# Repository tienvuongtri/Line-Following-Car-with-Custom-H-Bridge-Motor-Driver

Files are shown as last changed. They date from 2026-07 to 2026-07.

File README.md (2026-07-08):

# ESP32 Line-Following Robot with Custom H-Bridge

An autonomous and Bluetooth-controlled 4WD robot featuring a custom-designed H-Bridge motor driver, ultrasonic obstacle detection, and PID-based line tracking.

## 🛠️ Hardware Overview

* **Microcontroller:** ESP32 Development Board
* **Motor Driver:** Custom-designed L298N H-Bridge PCB
* **Line Sensor:** 5-Channel IR Sensor Array (Active Low logic)
* **Obstacle Detection:** HC-SR04 Ultrasonic Sensor
* **Actuators/Indicators:** 4x DC Motors, Buzzer, LED Indicator
* **Communication:** Bluetooth Classic (`ESP32_PRO_CAR`)

## 📍 Pin Mapping

| Component | ESP32 Pin | Component | ESP32 Pin |
| :--- | :--- | :--- | :--- |
| **Motor ENA** | GPIO 14 | **Sensor S1 (Far Left)** | GPIO 17 |
| **Motor ENB** | GPIO 32 | **Sensor S2 (Mid Left)** | GPIO 19 |
| **Motor IN1** | GPIO 27 | **Sensor S3 (Center)** | GPIO 4 |
| **Motor IN2** | GPIO 26 | **Sensor S4 (Mid Right)** | GPIO 16 |
| **Motor IN3** | GPIO 25 | **Sensor S5 (Far Right)**| GPIO 23 |
| **Motor IN4** | GPIO 33 | **Ultrasonic TRIG** | GPIO 5 |
| **Buzzer** | GPIO 15 | **Ultrasonic ECHO** | GPIO 18 |
| **LED** | GPIO 2 | | |

## 📂 Project Structure

* `xe_do_line_IC2005_G1/`: Arduino source code containing the PID algorithm, Bluetooth control logic, and sensor reading functions.
* `H-Bridge Module/`: KiCad 9 hardware design files, including schematics, PCB layout, and Gerber files for manufacturing the custom motor driver.
* `images/`: Real-world photos and 3D renderings of the hardware.

## 📸 Demonstration

**Custom H-Bridge PCB Design:**
<div align="center">
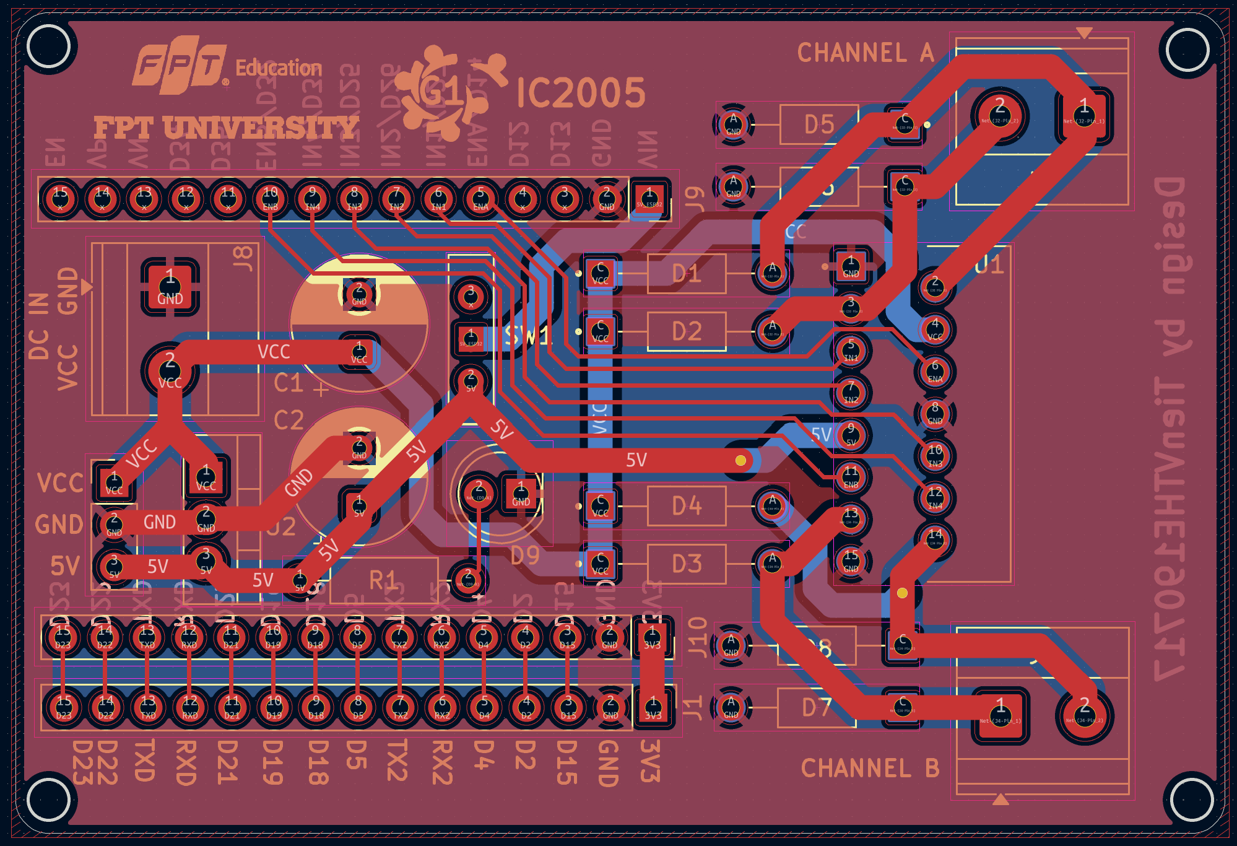
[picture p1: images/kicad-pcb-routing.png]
PCB Layout
  
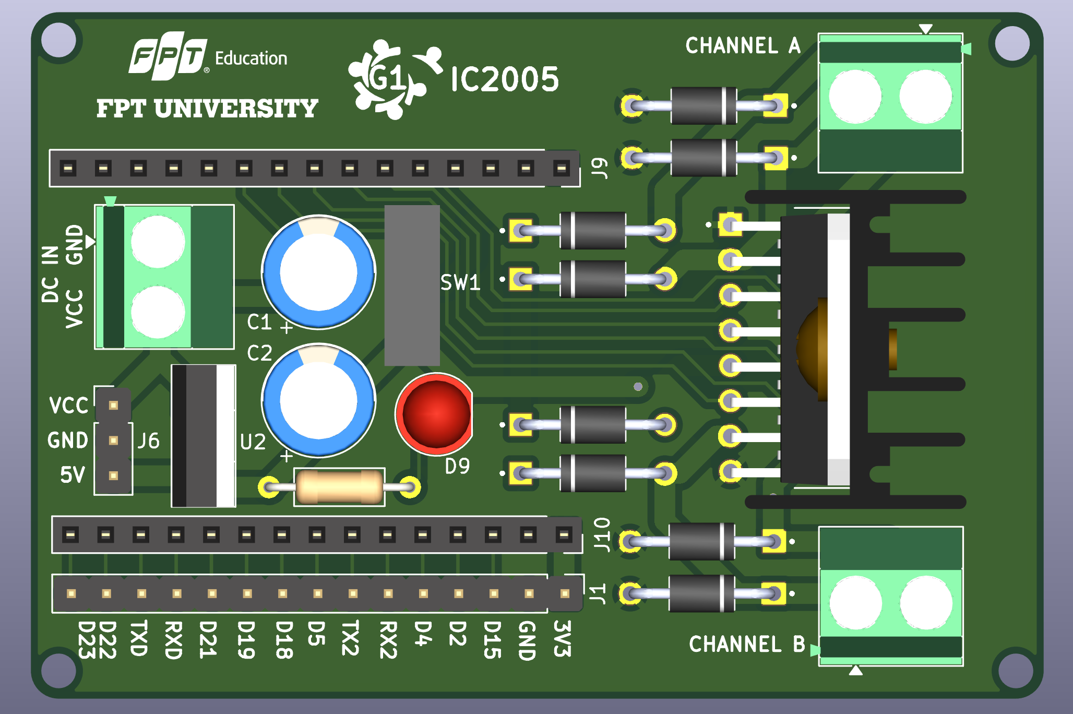
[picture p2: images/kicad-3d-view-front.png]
3D Front View
  
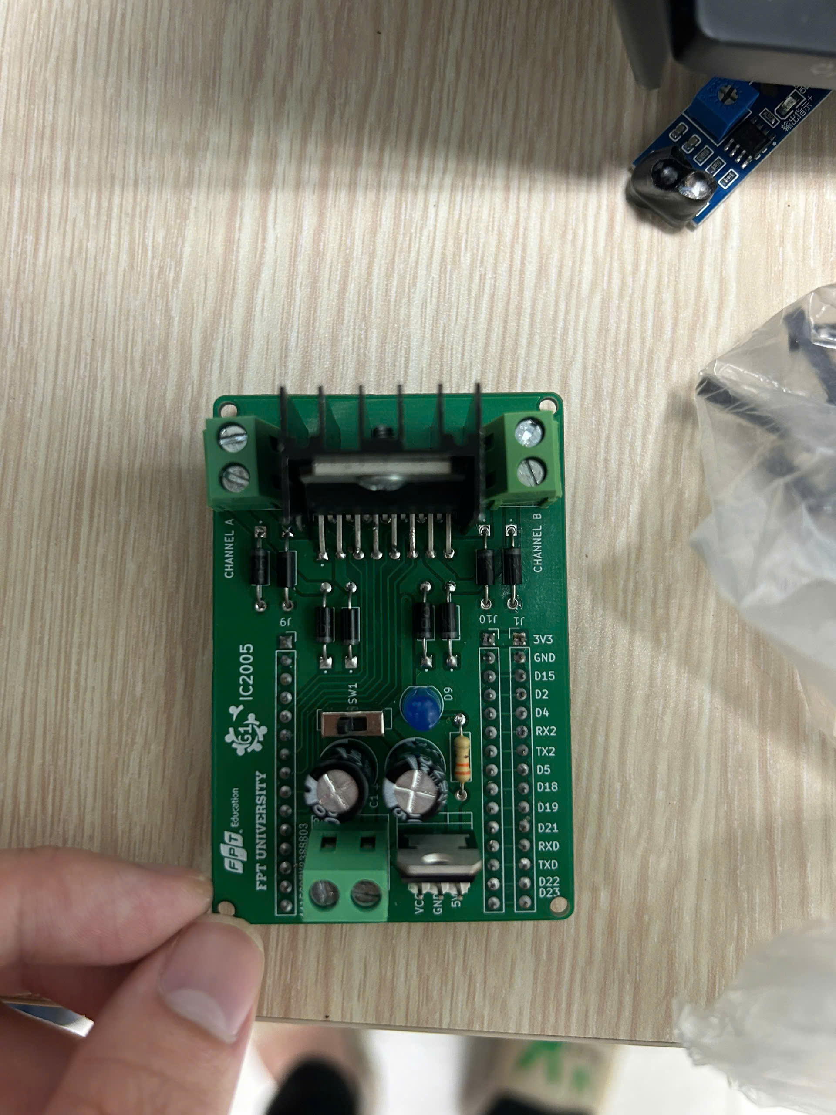
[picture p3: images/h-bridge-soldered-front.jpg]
Soldered PCB
  
</div>

**Robot Assembly:**
<div align="center">
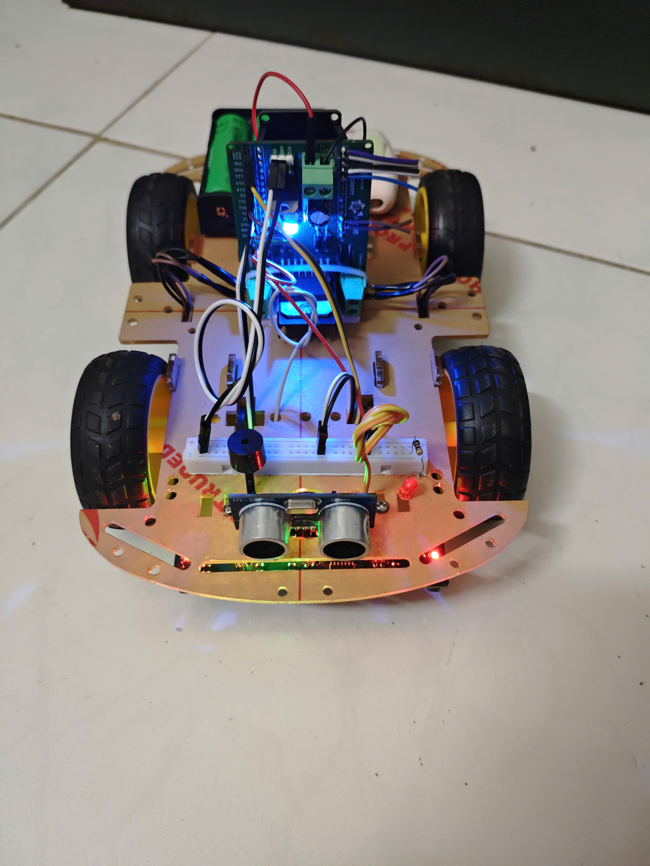
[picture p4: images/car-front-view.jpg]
Car Front View
  
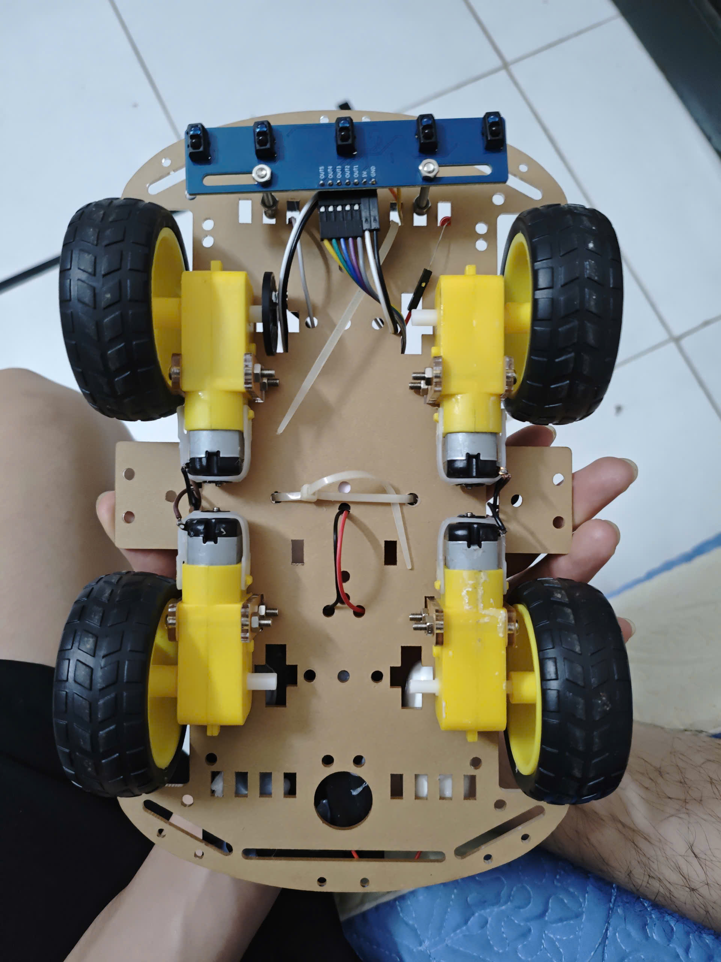
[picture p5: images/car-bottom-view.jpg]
Car Bottom View
  
</div>

## ⚙️ Features & Operation Modes

The system operates in two main modes, switchable via a custom Bluetooth serial application:

1.  **Line Following Mode (Mode 1):** Uses a PID control loop optimized with a dynamic time delta (`dt`) to track lines smoothly. Features pre-programmed intersection handling and step counting.
2.  **Manual / Bluetooth Mode (Mode 2):** Allows remote directional control with automatic forward obstacle detection (stops and alerts via buzzer/LED if an object is closer than 8 cm).

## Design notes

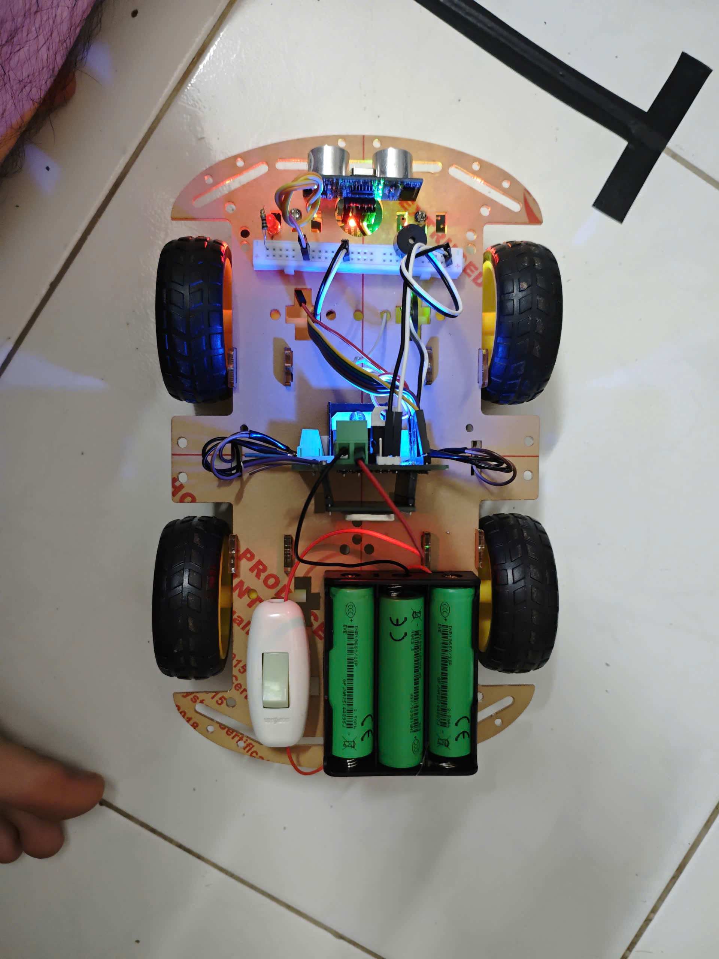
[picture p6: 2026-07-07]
images/car-chassis-layout.jpg

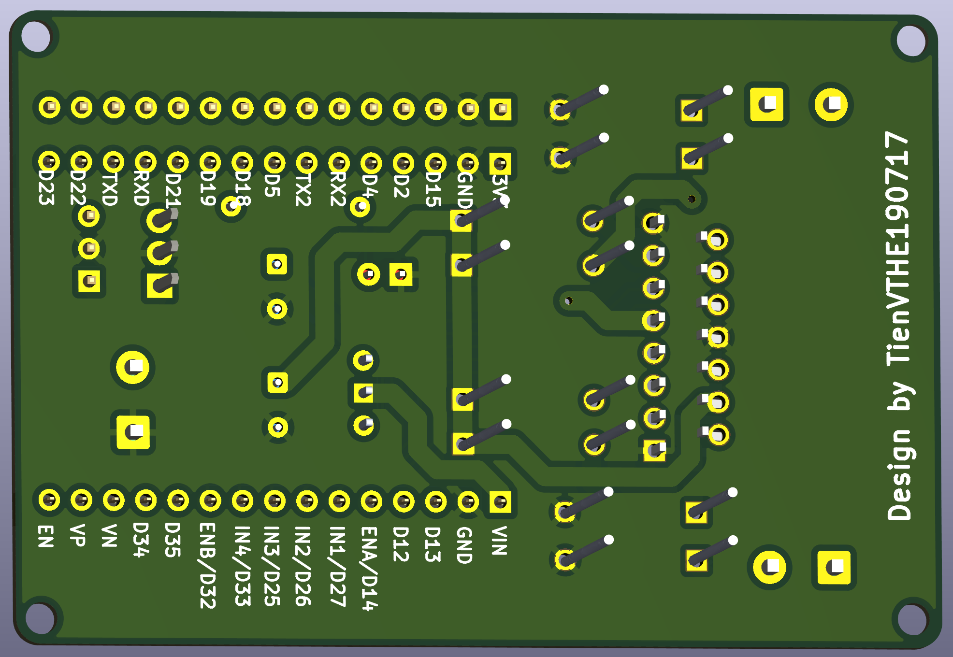
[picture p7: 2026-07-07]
images/kicad-3d-view-back.png

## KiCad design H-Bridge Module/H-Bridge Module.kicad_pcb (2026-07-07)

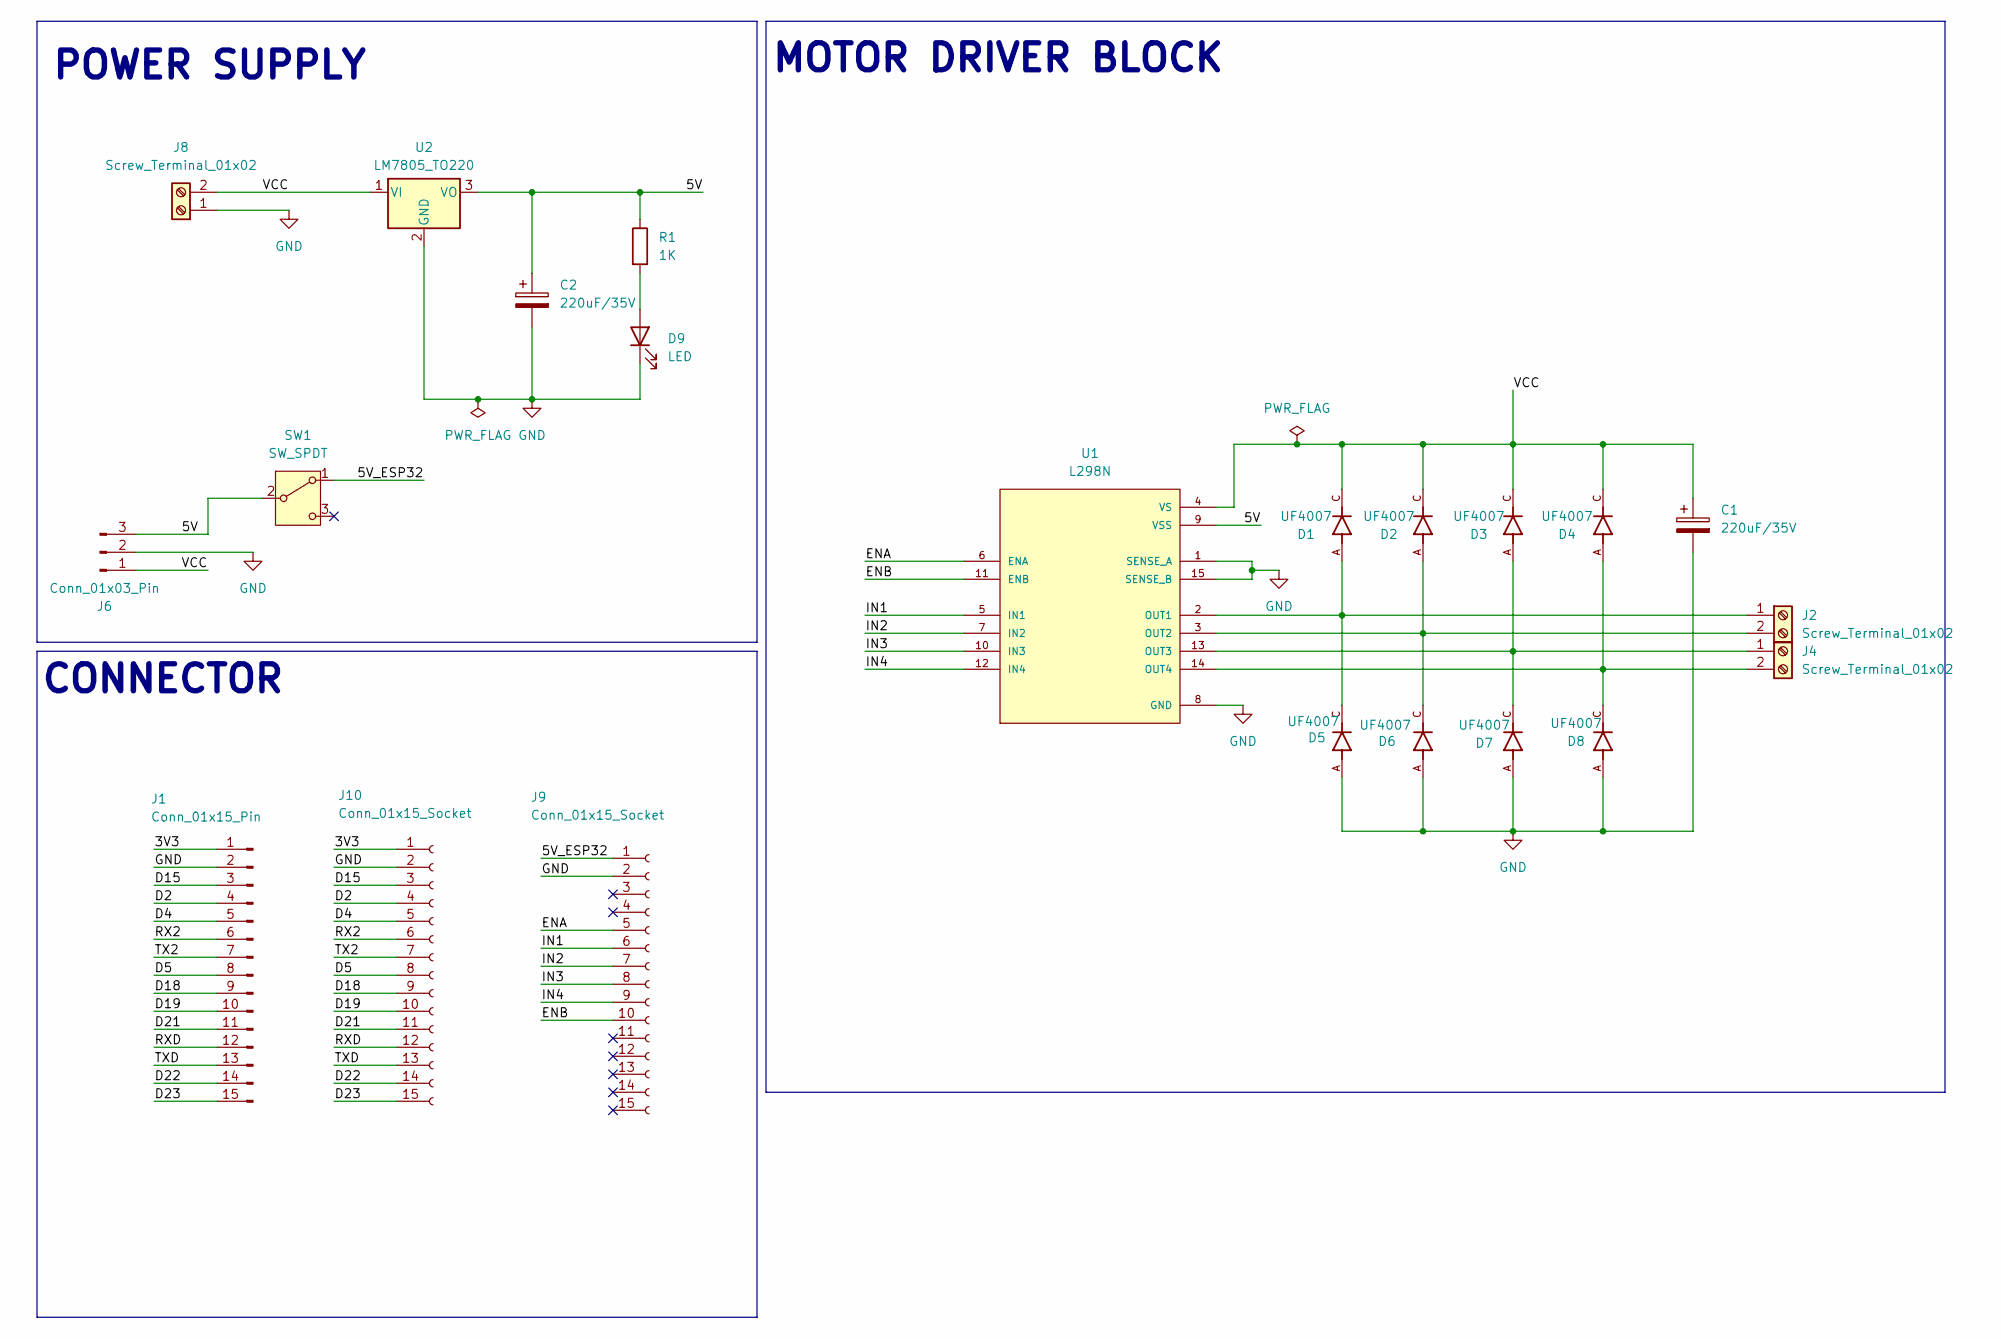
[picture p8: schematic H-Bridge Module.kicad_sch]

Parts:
C1, C2: 220uF/35V; CP_Radial_D8.0mm_P3.50mm
D1, D2, D3, D4, D5, D6, D7, D8: UF4007; DIOAD1036W78L470D235; PARTREV P2104
D9: LED; LED_D5.0mm
J1: Conn_01x15_Pin; PinHeader_1x15_P2.54mm_Vertical
J2, J4, J8: Screw_Terminal_01x02; TerminalBlock_Phoenix_MKDS-1,5-2-5.08_1x02_P5.08mm_Horizont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
J6: Conn_01x03_Pin; PinHeader_1x03_P2.54mm_Vertical
J9, J10: Conn_01x15_Socket; PinSocket_1x15_P2.54mm_Vertical
R1: 1K; R_Axial_DIN0207_L6.3mm_D2.5mm_P10.16mm_Horizontal
SW1: SW_SPDT; SW_Slide-03_Wuerth-WS-SLTV_10x2.5x6.4_P2.54mm
U1: L298N; TO127P2020X500X2100-15
U2: LM7805_TO220; TO-220-3_Vertical

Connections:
/3V3: J1.1, J10.1
/5V: C2.1, J6.3, R1.1, SW1.2 (B), U1.9 (VSS), U2.3 (VO)
/5V_ESP32: J9.1, SW1.1 (A)
/D2: J1.4, J10.4
/D4: J1.5, J10.5
/D5: J1.8, J10.8
/D15: J1.3, J10.3
/D18: J1.9, J10.9
/D19: J1.10, J10.10
/D21: J1.11, J10.11
/D22: J1.14, J10.14
/D23: J1.15, J10.15
/ENA: J9.5, U1.6 (ENA)
/ENB: J9.10, U1.11 (ENB)
/IN1: J9.6, U1.5 (IN1)
/IN2: J9.7, U1.7 (IN2)
/IN3: J9.8, U1.10 (IN3)
/IN4: J9.9, U1.12 (IN4)
/RX2: J1.6, J10.6
/RXD: J1.12, J10.12
/TX2: J1.7, J10.7
/TXD: J1.13, J10.13
/VCC: C1.1, D1.C, D2.C, D3.C, D4.C, J6.1, J8.2, U1.4 (VS), U2.1 (VI)
GND: C1.2, C2.2, D5.A, D6.A, D7.A, D8.A, D9.1 (K), J1.2, J6.2, J8.1, J9.2, J10.2, U1.1 (SENSE_A), U1.8 (GND), U1.15 (SENSE_B), U2.2 (GND)
unnamed: D9.2 (A), R1.2
unnamed: D1.A, D5.C, J2.1, U1.2 (OUT1)
unnamed: D2.A, D6.C, J2.2, U1.3 (OUT2)
unnamed: D3.A, D7.C, J4.1, U1.13 (OUT3)
unnamed: D4.A, D8.C, J4.2, U1.14 (OUT4)

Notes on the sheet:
CONNECTOR
POWER SUPPLY
MOTOR DRIVER BLOCK

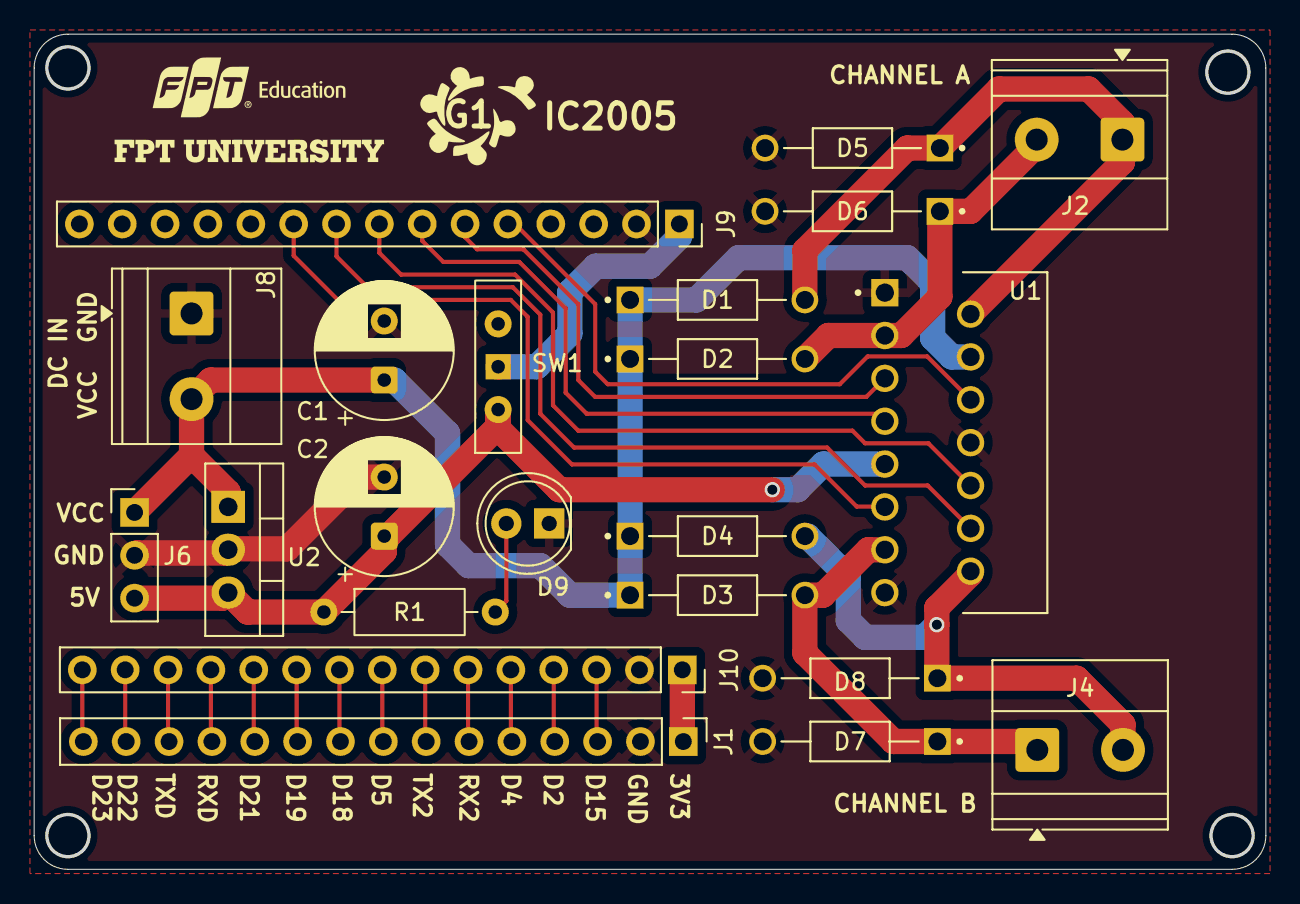
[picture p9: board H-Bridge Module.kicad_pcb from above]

Board: 2 copper layers, 73.0 x 49.5 mm, 23 parts (0 on the bottom side), 29 nets.

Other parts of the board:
G1: LOGO; logo_G1

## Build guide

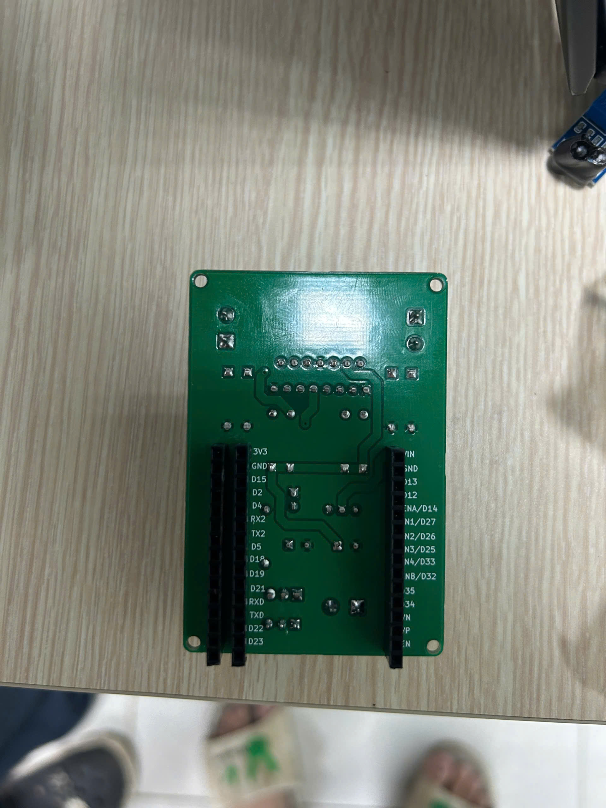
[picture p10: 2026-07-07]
images/h-bridge-soldered-back.jpg

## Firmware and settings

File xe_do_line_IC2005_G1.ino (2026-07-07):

#include "BluetoothSerial.h"

// ==================== KHAI BÁO PIN ĐỘNG CƠ (GIỮ NGUYÊN) ====================
BluetoothSerial SerialBT;

#define ENA  14
#define IN1  27
#define IN2  26
#define IN3  25
#define IN4  33
#define ENB  32

// ==================== KHAI BÁO PIN CẢM BIẾN ====================
#define S1 17   // Trái ngoài cùng
#define S2 19   // Trái trong
#define S3 4    // Giữa
#define S4 16   // Phải trong
#define S5 23   // Phải ngoài cùng

#define TRIG   5
#define ECHO   18
#define BUZZER 15
#define LED    2

// ==================== PWM ESP32 ====================
#define PWM_CHANNEL_A 0
#define PWM_CHANNEL_B 1
#define PWM_FREQ 1000
#define PWM_RES 8

// ==================== BIẾN TOÀN CỤC & PID ====================
int systemMode = 0;        
int SPEED_BASE = 120; // Lấy theo initial_motor_speed của code mẫu
int manualSpeed = 180;
char lastCmd = 'S';
int stepCounter = 1; 
unsigned long lastCrossTime = 0; 


// Các thông số PID từ code mẫu (Bạn có thể cần tinh chỉnh lại Kd trên sân)
float Kp = 20.0;
float Ki = 0.3;
float Kd = 50.0;

int error = 0;
int previous_error = 0;
float P = 0, I = 0, D = 0;
float PID_value = 0;

unsigned long lastPingTime = 0;
unsigned long lastTimePID = 0; 
float currentDist = 999;
float dt = 0;

// ==================== HÀM HỖ TRỢ ====================
void setAlarm(bool state) {
  digitalWrite(BUZZER, state ? HIGH : LOW);
  digitalWrite(LED, state ? HIGH : LOW);
}

void beep(int ms) {
  setAlarm(true); delay(ms); setAlarm(false);
}

// Hàm motor đã được tối ưu để dùng cho ESP32 và hỗ trợ quay ngược (âm)
void motor(int left, int right) {
  digitalWrite(IN1, left >= 0 ? HIGH : LOW);
  digitalWrite(IN2, left >= 0 ? LOW  : HIGH);
  ledcWrite(PWM_CHANNEL_A, abs(left));

  digitalWrite(IN3, right >= 0 ? HIGH : LOW);
  digitalWrite(IN4, right >= 0 ? LOW  : HIGH);
  ledcWrite(PWM_CHANNEL_B, abs(right));
}

void stopM() {
  motor(0, 0);
}

float getDistance() {
  digitalWrite(TRIG, LOW); delayMicroseconds(2);
  digitalWrite(TRIG, HIGH); delayMicroseconds(10);
  digitalWrite(TRIG, LOW);
  long t = pulseIn(ECHO, HIGH, 4000); 
  return (t == 0) ? 999 : t * 0.034 / 2.0;
}


// ==================== DÒ LINE SA HÌNH FPT ====================
void lineFollow() {
  int l1 = digitalRead(S1); 
  int l2 = digitalRead(S2); 
  int l3 = digitalRead(S3); 
  int l4 = digitalRead(S4); 
  int l5 = digitalRead(S5); 

  // 1. NHẬN DIỆN GIAO CẮT & ĐẾM BƯỚC
  // Nếu mắt ngoài cùng chạm vạch VÀ đã qua ít nhất 0.8s kể từ ngã rẽ trước (chống đếm đúp)
  if ((l1 == 0 || l5 == 0) && (millis() - lastCrossTime > 800)) {
    lastCrossTime = millis(); // Reset đồng hồ

    // Thực hiện lệnh rẽ tương ứng với từng chốt trên chữ FPT
    switch(stepCounter) {
      
      case 1: // CHỐT 1: Ngã 3 giữa chữ F -> Phải rẽ Phải
        motor(180, -180); delay(150); 
        while(digitalRead(S3) == 1) { motor(180, -180); }
        break;

      case 2: // CHỐT 2: Góc gập 45 độ lên chéo -> Phải rẽ Trái
        motor(-180, 180); delay(100); // Delay ngắn hơn vì góc 45 độ
        while(digitalRead(S3) == 1) { motor(-180, 180); }
        break;

      case 3: // CHỐT 3 (BẪY): Đâm chéo vào chữ P -> Ép rẽ Trái (Đi lên)
        motor(-180, 180); delay(150); 
        while(digitalRead(S3) == 1) { motor(-180, 180); }
        break;

      case 4: // CHỐT 4: Đỉnh chữ P -> Rẽ Phải
        motor(180, -180); delay(150); 
        while(digitalRead(S3) == 1) { motor(180, -180); }
        break;

      case 5: // CHỐT 5: Cắt ngang thân chữ T -> ÉP ĐI THẲNG QUA
        motor(SPEED_BASE, SPEED_BASE);
        delay(200); // Lướt qua vạch ngang mà không bẻ lái
        break;

      case 6: // CHỐT 6: Đỉnh nhọn chữ T -> Rẽ Phải góc gắt 135 độ
        motor(180, -180); delay(200); // Delay lâu hơn để quay sâu vào trong
        while(digitalRead(S3) == 1) { motor(180, -180); }
        break;

      case 7: // CHỐT 7 (BẪY): Đâm chéo vào thân chữ T -> Ép rẽ Trái (Đi xuống Finish)
        motor(-180, 180); delay(150); 
        while(digitalRead(S3) == 1) { motor(-180, 180); }
        break;
    }

    // Tăng bộ đếm cho ngã rẽ tiếp theo, đặt lại lỗi PID để xe chạy thẳng mượt
    stepCounter++;
    previous_error = 0;
    lastTimePID = micros(); 
    return; // Rẽ xong thì thoát luôn, nhường vòng lặp tiếp theo cho PID
  }

  // 2. NẾU MẤT VẠCH TRÊN ĐƯỜNG ĐI (Khắc phục sự cố)
  if (l5 == 1 && l4 == 1 && l3 == 1 && l2 == 1 && l1 == 1) {
    if (previous_error > 0) { error = 5; } 
    else if (previous_error < 0) { error = -5; }
  }

  // 3. TÍNH TOÁN LỖI CHO ĐOẠN ĐƯỜNG THẲNG/CHÉO
  else {
    if      (l5 == 1 && l4 == 1 && l3 == 1 && l2 == 1 && l1 == 0) { error = 4; }
    else if (l5 == 1 && l4 == 1 && l3 == 1 && l2 == 0 && l1 == 0) { error = 3; }
    else if (l5 == 1 && l4 == 1 && l3 == 1 && l2 == 0 && l1 == 1) { error = 2; }
    else if (l5 == 1 && l4 == 1 && l3 == 0 && l2 == 0 && l1 == 1) { error = 1; }
    else if (l5 == 1 && l4 == 1 && l3 == 0 && l2 == 1 && l1 == 1) { error = 0; }
    else if (l5 == 1 && l4 == 0 && l3 == 0 && l2 == 1 && l1 == 1) { error = -1; }
    else if (l5 == 1 && l4 == 0 && l3 == 1 && l2 == 1 && l1 == 1) { error = -2; }
    else if (l5 == 0 && l4 == 0 && l3 == 1 && l2 == 1 && l1 == 1) { error = -3; }
    else if (l5 == 0 && l4 == 1 && l3 == 1 && l2 == 1 && l1 == 1) { error = -4; }
  }

  // 4. CHẠY PID ĐỂ GIỮ THĂNG BẰNG
  unsigned long now = micros();
  dt = (now - lastTimePID) / 1000000.0;
  if (dt <= 0.0 || dt > 0.1) dt = 0.005; 
  lastTimePID = now;

  P = error;
  I = I + error * dt;
  D = (error - previous_error) / dt; 
  I = constrain(I, -50, 50); 
  
  PID_value = Kp * P + Ki * I + Kd * D;
  previous_error = error;

  PID_value = constrain(PID_value, -180, 180);

  int leftSpeed  = SPEED_BASE - PID_value;
  int rightSpeed = SPEED_BASE + PID_value;
  leftSpeed  = constrain(leftSpeed, -255, 255);
  rightSpeed = constrain(rightSpeed, -255, 255);

  motor(leftSpeed, rightSpeed);
}

// ==================== SETUP & LOOP ====================
void setup() {
  Serial.begin(115200);
  SerialBT.begin("ESP32_PRO_CAR");

  pinMode(IN1, OUTPUT); pinMode(IN2, OUTPUT);
  pinMode(IN3, OUTPUT); pinMode(IN4, OUTPUT);

  ledcSetup(PWM_CHANNEL_A, PWM_FREQ, PWM_RES);
  ledcAttachPin(ENA, PWM_CHANNEL_A);
  ledcSetup(PWM_CHANNEL_B, PWM_FREQ, PWM_RES);
  ledcAttachPin(ENB, PWM_CHANNEL_B);

  pinMode(S1, INPUT); pinMode(S2, INPUT); pinMode(S3, INPUT);
  pinMode(S4, INPUT); pinMode(S5, INPUT);

  pinMode(TRIG, OUTPUT); pinMode(ECHO, INPUT);
  pinMode(BUZZER, OUTPUT); pinMode(LED, OUTPUT);

  stopM();
  beep(300);
  lastTimePID = micros(); 
}

void loop() {
  if (SerialBT.available()) {
    char cmd = SerialBT.read();
    if (cmd == '1') { systemMode = 1; beep(100); }
    else if (cmd == '0') { systemMode = 0; stopM(); beep(500); }
    else if (cmd=='F'||cmd=='B'||cmd=='L'||cmd=='R'||cmd=='S') {
      systemMode = 2; lastCmd = cmd;
      switch(cmd) {
        case 'F': motor(manualSpeed, manualSpeed); break;
        case 'B': motor(-manualSpeed, -manualSpeed); break;
        case 'L': motor(-manualSpeed, manualSpeed); break;
        case 'R': motor(manualSpeed, -manualSpeed); break;
        case 'S': stopM(); break;
      }
    }
  }

  if (systemMode == 1) {
    if (millis() - lastPingTime > 60) {
      currentDist = getDistance();
      lastPingTime = millis();
    }
    if (currentDist < 15.0) {
      stopM(); beep(200);
      motor(-100, -100); delay(300);
      motor(-130, 130); delay(450);
      currentDist = 999;
      lastTimePID = micros(); 
    } else {
      lineFollow();
    }
  }
  else if (systemMode == 2) {
    float dist = getDistance();
    if (dist < 8.0 && lastCmd == 'F') {
      setAlarm(true); stopM();
    } else {
      setAlarm(false);
    }
  }
  delay(4);
}

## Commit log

2026-07-07 Initial commit:PID line-following car code and H-Bridge module extention
    [H-Bridge Module-B_Cu.gbr, H-Bridge Module-B_Mask.gbr, H-Bridge Module-B_Paste.gbr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]
2026-07-07 Add real photos of the custom H-Bridge board and the car
